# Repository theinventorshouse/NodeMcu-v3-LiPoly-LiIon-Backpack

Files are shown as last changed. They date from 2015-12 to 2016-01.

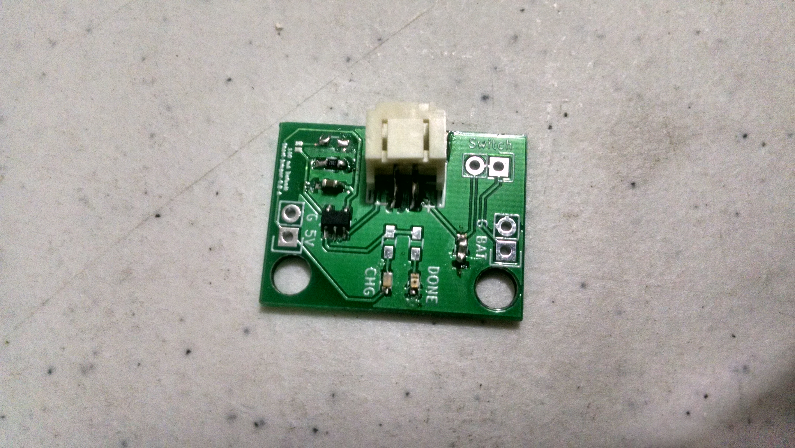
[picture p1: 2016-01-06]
Photos Rev.A Testing/IMG_20151228_190609534_HDR.jpg

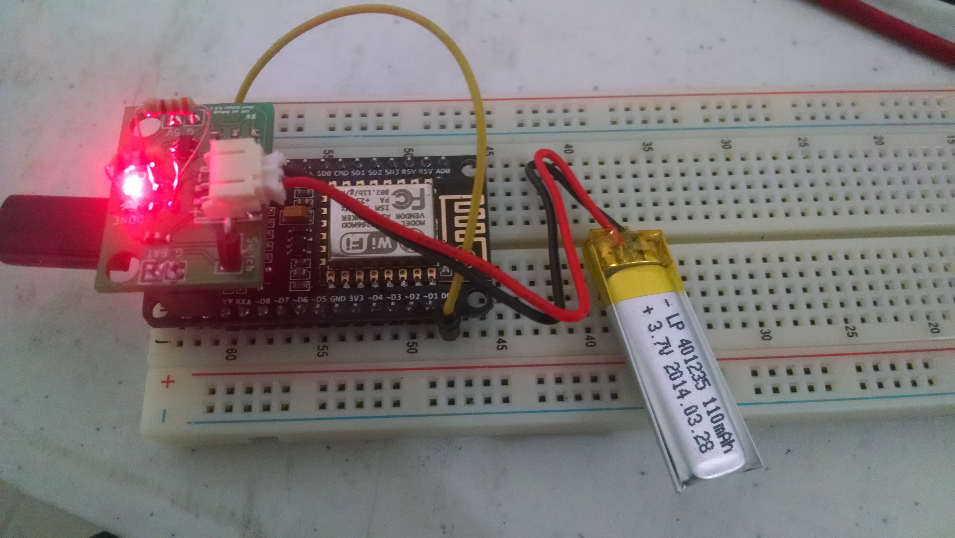
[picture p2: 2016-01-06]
Photos Rev.A Testing/IMG_20151229_141519252.jpg

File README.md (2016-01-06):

# NodeMCU DEVKIT V1.0 LiPoly LiIon Backpack
ESP8266 NodeMCU DEVKIT V1.0 (or Node Mcu V3) LiPoly/LiIon Backpack



The Inventor's House invests time and resources providing this open source code,
please support The Inventor's House and open-source hardware by purchasing
products from The Inventor's House!

Designed by The Inventor's House.
CERN Open Hardware Licence 1.2 (CERN OHL 1.2), check cern_ohl_v_1_2.txt for more information All text above must be included in any redistribution

Order the pc board from SeedStudio and assemble your own or order the fully assembled and tested LiPo charger from me and see what fast LiPo battery charging can do for your application!

Use Library Kicad
____________

https://github.com/sabas1080/kicadlibrary

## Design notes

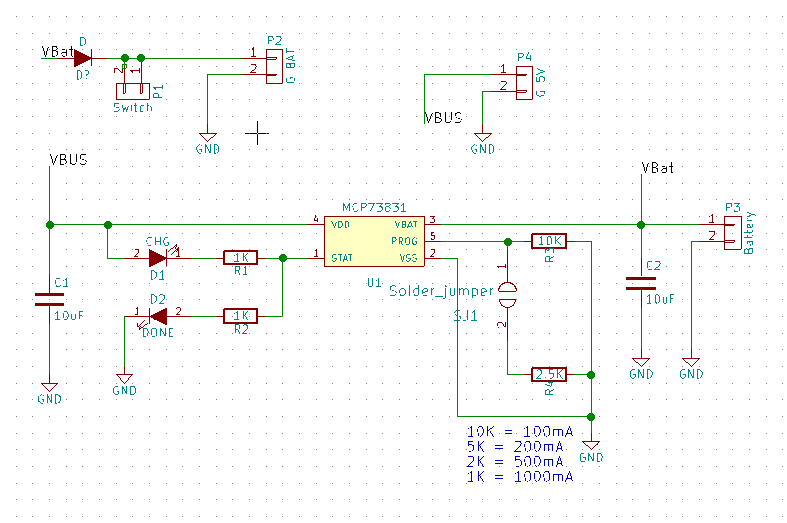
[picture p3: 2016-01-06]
SchematicRevA.png

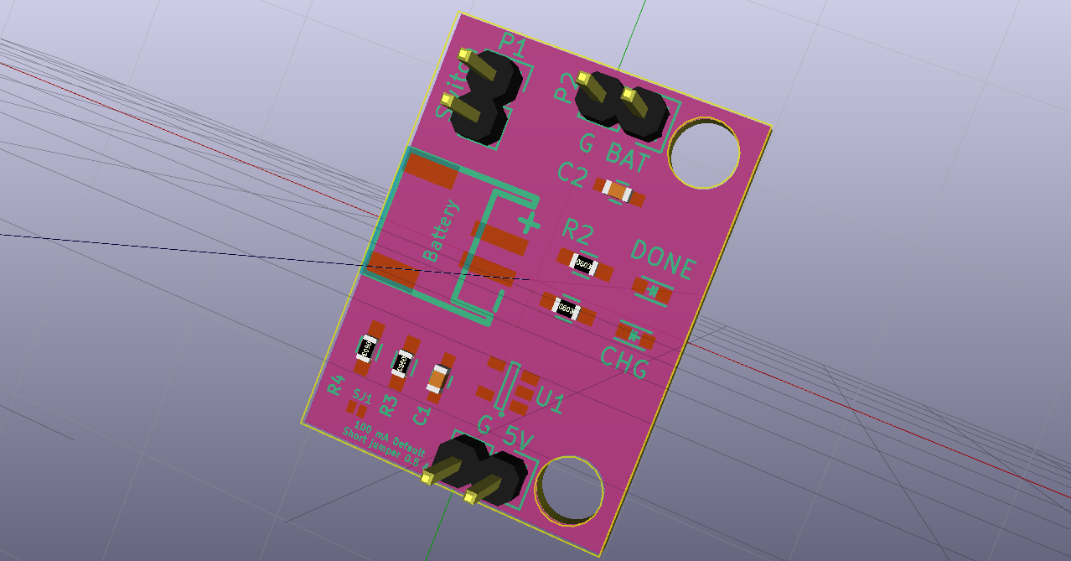
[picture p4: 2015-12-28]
NodeMcuLiPolyBackpack.png

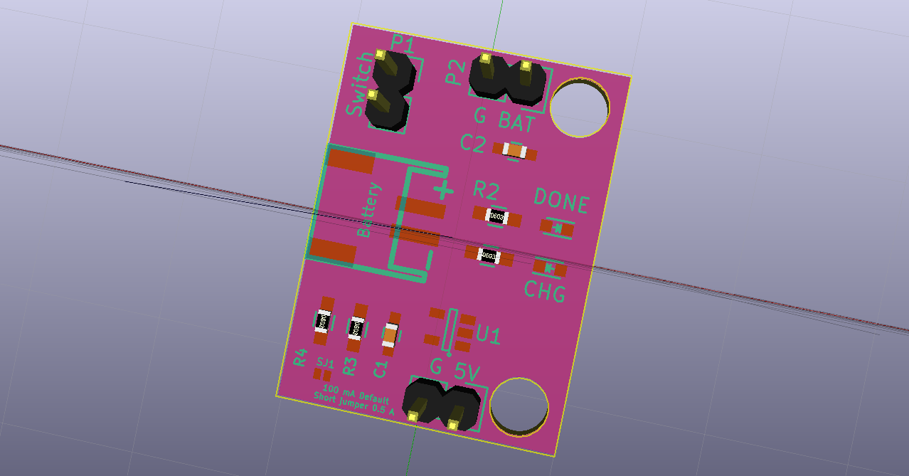
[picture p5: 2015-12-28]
NodeMcuLiPolyBackpack2.png

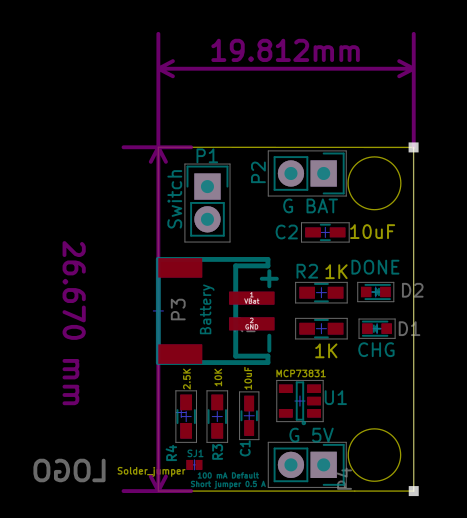
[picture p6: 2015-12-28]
PCBNew.png

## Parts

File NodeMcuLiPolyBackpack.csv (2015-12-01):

Id | Designator | Package | Quantity | Designation | Supplier and ref
1 | C1,C2 | C_0603_HandSoldering | 2 | 10uF
2 | D1 | LED-0603 | 1 | CHG
3 | D2 | LED-0603 | 1 | DONE
4 | P1 | Pin_Header_Straight_1x02 | 1 | Switch
5 | P2 | Pin_Header_Straight_1x02 | 1 | G BAT
6 | P3 | CONN_JST-2_SMD | 1 | Battery
7 | P4 | Pin_Header_Straight_1x02 | 1 | G 5V
8 | R1,R2 | R_0603_HandSoldering | 2 | 1K
9 | R3 | R_0603_HandSoldering | 1 | 10K
10 | R4 | R_0603_HandSoldering | 1 | 2.5K
11 | SJ1 | S_JUMPER_2 | 1 | Solder_jumper
12 | U1 | SOT-23-5 | 1 | MCP73831
13 | LOGO | LOGO | 1

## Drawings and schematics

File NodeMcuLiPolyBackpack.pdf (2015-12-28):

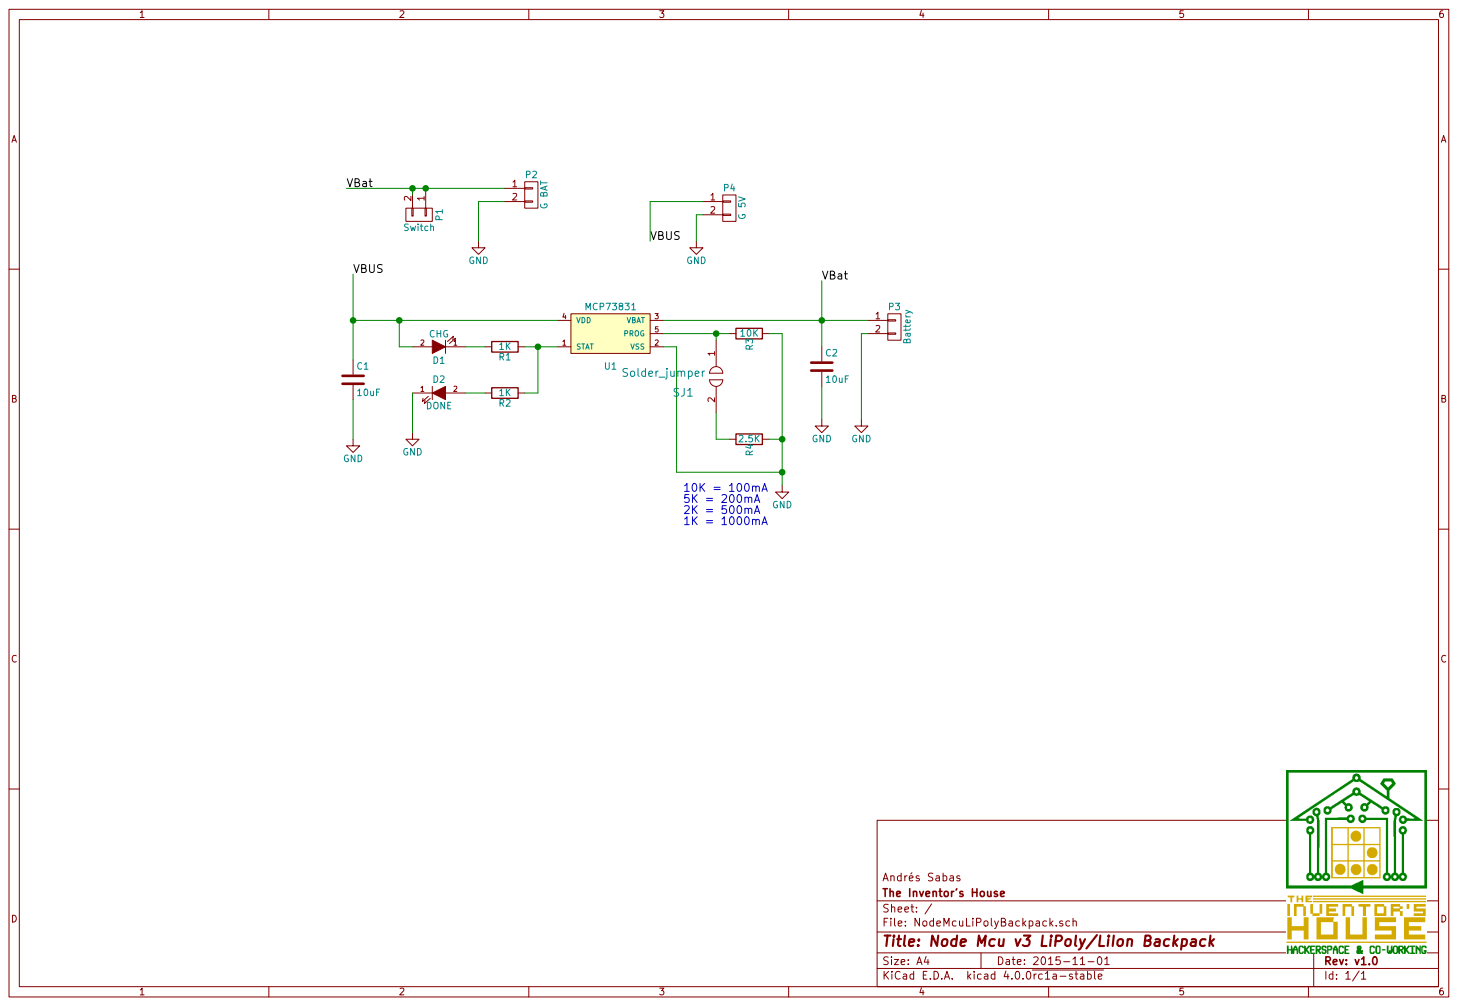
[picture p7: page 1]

File: NodeMcuLiPolyBackpack.sch Sheet: / The Inventor's House Andrés Sabas

Id: 1/1 Title: Node Mcu v3 LiPoly/LiIon Backpack

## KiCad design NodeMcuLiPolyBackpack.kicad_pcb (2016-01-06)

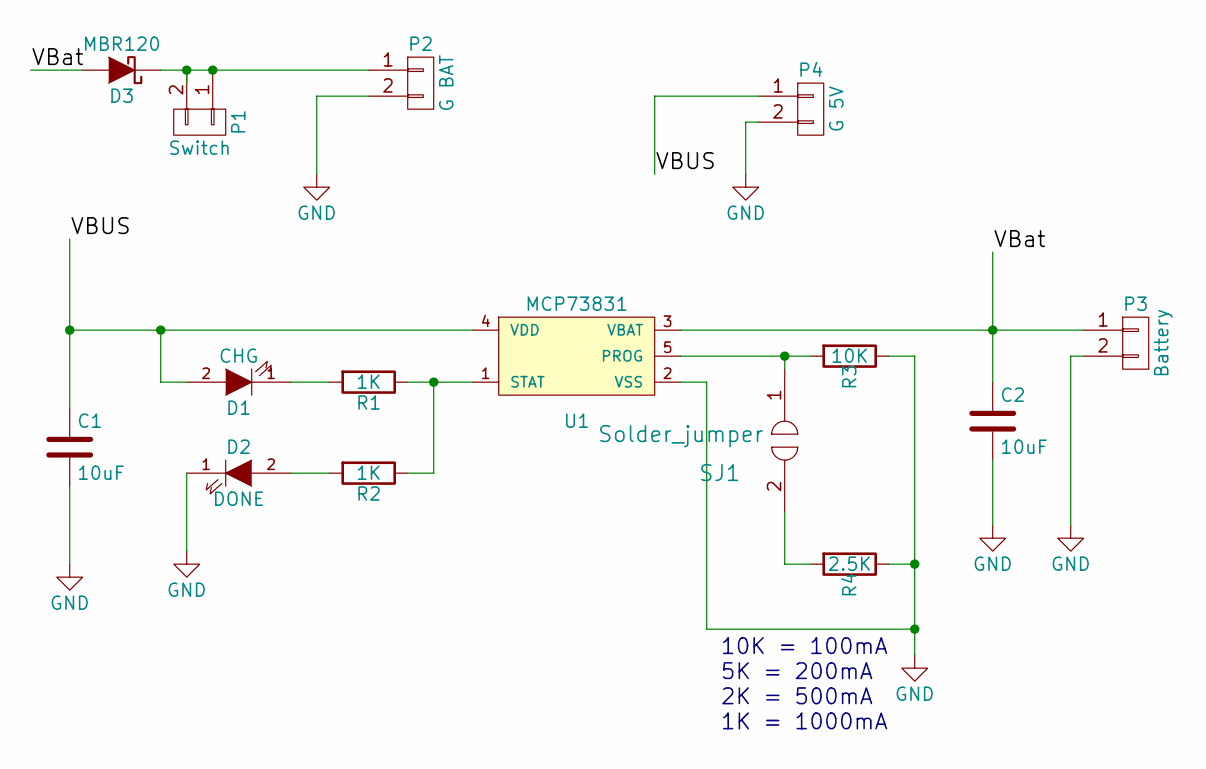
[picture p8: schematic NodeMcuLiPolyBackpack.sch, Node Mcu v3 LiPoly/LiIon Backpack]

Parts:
C1, C2: 10uF; C_0603_HandSoldering
D1: CHG; LED-0603
D2: DONE; LED-0603
D3: MBR120; SOD-123
P1: Switch; Pin_Header_Straight_1x02
P2: G BAT; Pin_Header_Straight_1x02
P3: Battery; CONN_JST-2_SMD
P4: G 5V; Pin_Header_Straight_1x02
R1, R2: 1K; R_0603_HandSoldering
R3: 10K; R_0603_HandSoldering
R4: 2.5K; R_0603_HandSoldering
SJ1: Solder_jumper; S_JUMPER_2
U1: MCP73831; SOT-23-5

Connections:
/VBUS: C1.1, D1.2 (A), P4.1, U1.4 (VDD)
/VBat: C2.1, D3.2 (A), P3.1, U1.3 (VBAT)
GND: C1.2, C2.2, D2.1 (K), P2.2, P3.2, P4.2, R3.1, R4.1, U1.2 (VSS)
unnamed: D1.1 (K), R1.2
unnamed: D2.2 (A), R2.2
unnamed: D3.1 (K), P1.1, P1.2, P2.1
unnamed: R1.1, R2.1, U1.1 (STAT)
unnamed: R3.2, SJ1.1, U1.5 (PROG)
unnamed: R4.2, SJ1.2

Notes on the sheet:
10K = 100mA 5K = 200mA 2K = 500mA 1K = 1000mA

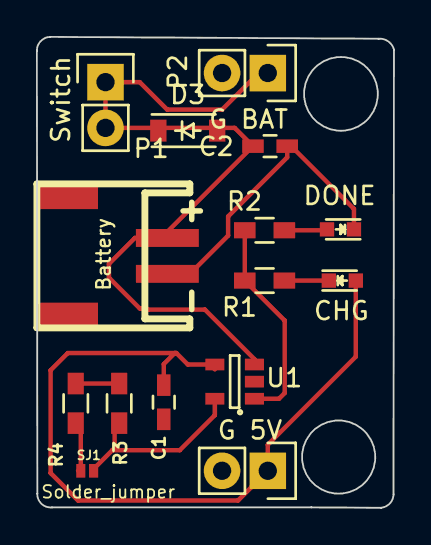
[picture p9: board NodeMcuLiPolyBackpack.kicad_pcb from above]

Board: 2 copper layers, 19.8 x 26.2 mm, 16 parts (1 on the bottom side), 9 nets.

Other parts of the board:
LOGO: LOGO

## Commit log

2015-11-02 Primer commit, esquematico listo
    [NodeMcuLiPolyBackpack.kicad_pcb, NodeMcuLiPolyBackpack.sch]
2015-11-03 Fix connector, add PCB
    [NodeMcuLiPolyBackpack.kicad_pcb, NodeMcuLiPolyBackpack.sch]
2015-11-11 Agregados medidas de orificios y pines.
    [NodeMcuLiPolyBackpack.kicad_pcb]
2015-11-11 Revision de Medidas de pines
2015-11-11 Logo, reacomodo v1.0
    [NodeMcuLiPolyBackpack.kicad_pcb, NodeMcuLiPolyBackpack.sch]
2015-11-11 Fix autosave
    [NodeMcuLiPolyBackpack.kicad_pcb]
2015-11-11 Fix F-slinks
    [NodeMcuLiPolyBackpack.kicad_pcb]
2015-12-01 Update Documents
    [NodeMcuLiPolyBackpack.csv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]
2015-12-28 Fix size
    [NodeMcuLiPolyBackpack.kicad_pcb, NodeMcuLiPolyBackpack.sch]
